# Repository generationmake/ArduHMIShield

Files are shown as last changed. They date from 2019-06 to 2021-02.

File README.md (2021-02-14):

# ArduHMIShield
ArduHMIShield with EA DOGM graphic display and joystick compatible to Arduino Uno

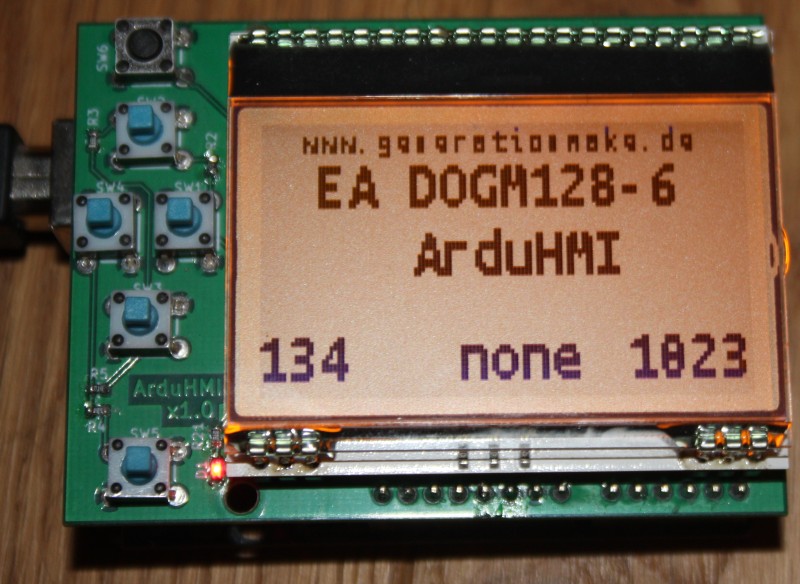
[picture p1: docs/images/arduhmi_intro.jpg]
ArduHMIShield intro


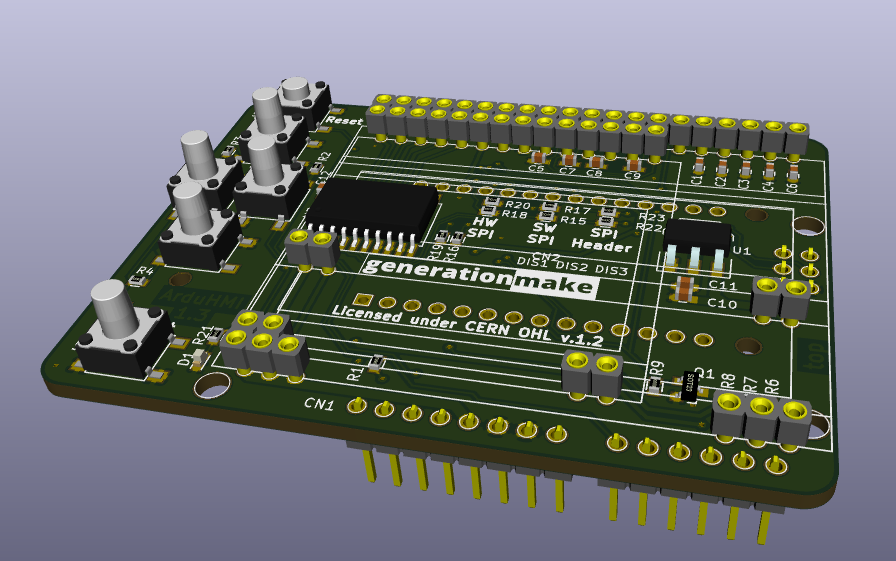
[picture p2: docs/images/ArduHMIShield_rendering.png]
ArduHMIShield rendering


### Holder

The holder is constructed using FreeCAD. It is 3D-printable. The files are in the folder `production-data`

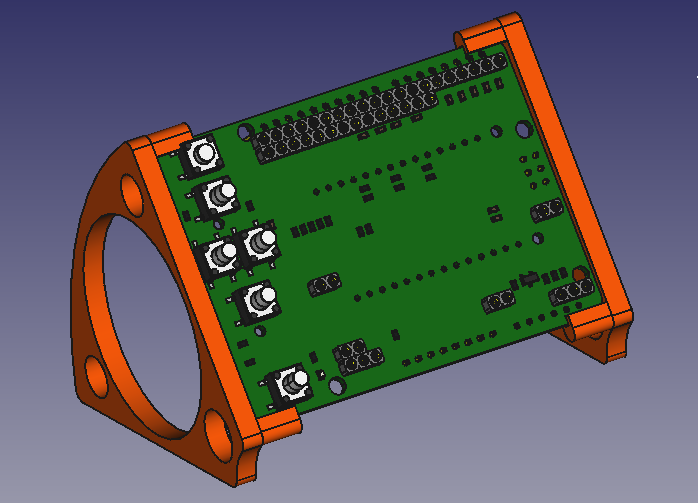
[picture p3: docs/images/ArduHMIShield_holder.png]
ArduHMIShield PCB holder


## PCB

### Top

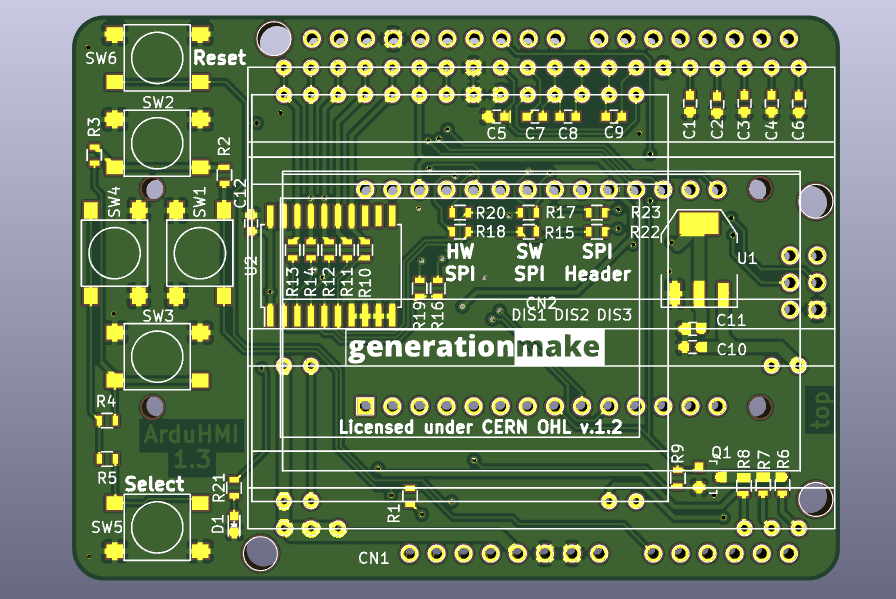
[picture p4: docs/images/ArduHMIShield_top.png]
ArduHMIShield PCB top


### Bottom

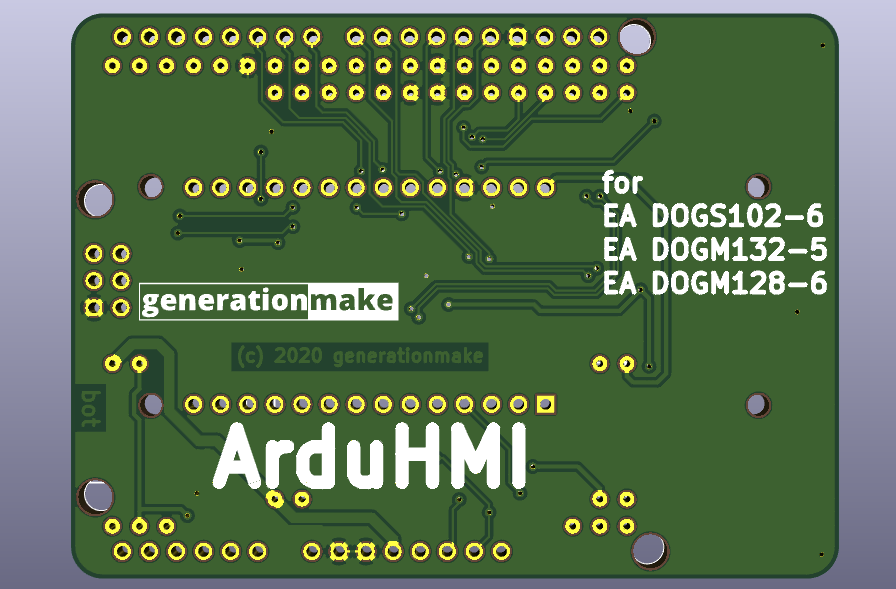
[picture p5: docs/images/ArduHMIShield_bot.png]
ArduHMIShield PCB bot


### Order options

The pcb is available at Aisler: https://aisler.net/p/FNAGFCPP

## License

This hardware is licensed under the CERN OHL v. 1.2

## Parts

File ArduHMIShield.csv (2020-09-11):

Id | Designator | Package | Quantity | Designation | Supplier and ref
1 | CN1 | ARDUINO_ISP_TOP | 1 | ARDUINO_ISP
2 | U2 | SOIC-20_7.5x12.8mm_Pitch1.27mm | 1 | 74VHC245D
3 | Q1 | SOT-23 | 1 | 2N7002
4 | C1,C2,C3,C4,C5,C6,C7,C8,C9,C10,C11 | C_0603 | 11 | 1uF
5 | R1 | R_0603 | 1 | 2k
6 | R2 | R_0603 | 1 | 330
7 | R3 | R_0603 | 1 | 620
8 | R6,R7,R8 | R_0603 | 3 | 30
9 | R9,R4,R21 | R_0603 | 3 | 1k
10 | R5 | R_0603 | 1 | 3k3
11 | DIS1 | EA_DOGM128 | 1 | EA_DOGM128-6
12 | DIS2 | EA_DOGM081_162_163_132 | 1 | EA_DOGM132-5
13 | DIS3 | EA_DOGS102 | 1 | EA_DOGS102-6
14 | U1 | SOT-223 | 1 | AZ1117IH-3.3
15 | C12 | C_0603 | 1 | 100nF
16 | R10,R11,R12,R13,R14,R15,R17,R19,R22,R23 | R_0603 | 10 | DNI
17 | R16,R18,R20 | R_0603 | 3 | 0R
18 | D1 | LED_0603 | 1 | 150060GS75000
19 | SW6 | WE_430182050816 | 1 | TAST_VER
20 | SW1,SW2,SW3,SW4,SW5 | WE_430182080816 | 5 | TAST_VER
21 | CN2 | ARDUINO_MKR_HOLES | 1 | ARDUINO_MKR
22 | L1,L2 | generationmake_logo | 2 | Label

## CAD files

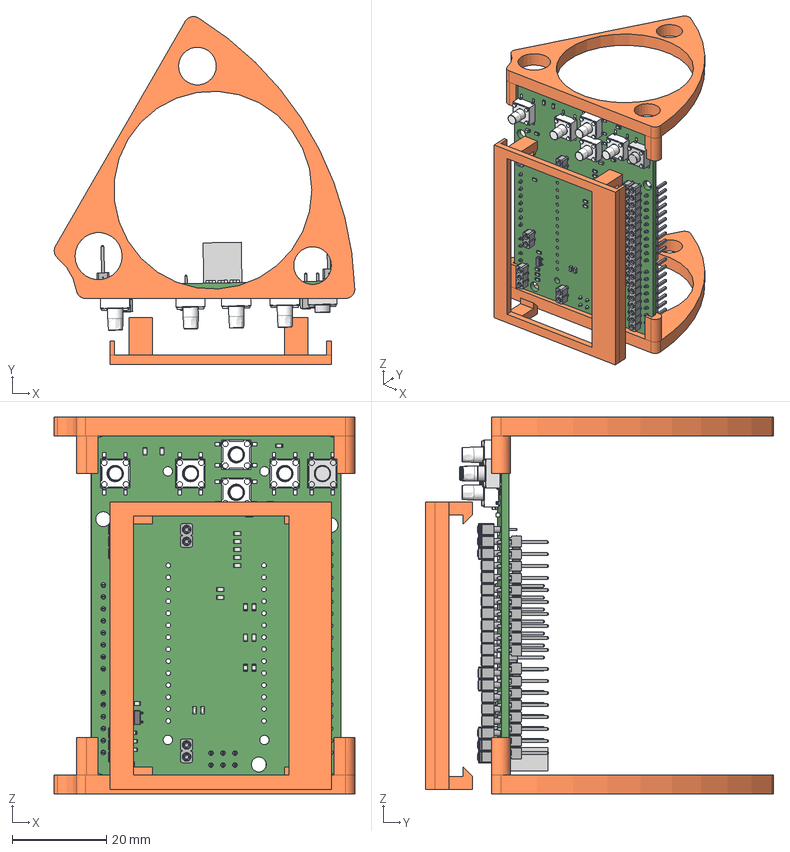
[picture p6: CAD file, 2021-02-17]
freecad_source/ArduHMI_holder.FCStd
63.8 x 73.9 x 80.0 mm
holder_right
holder_left
mainframe
clip
clip001
clip002
clip003

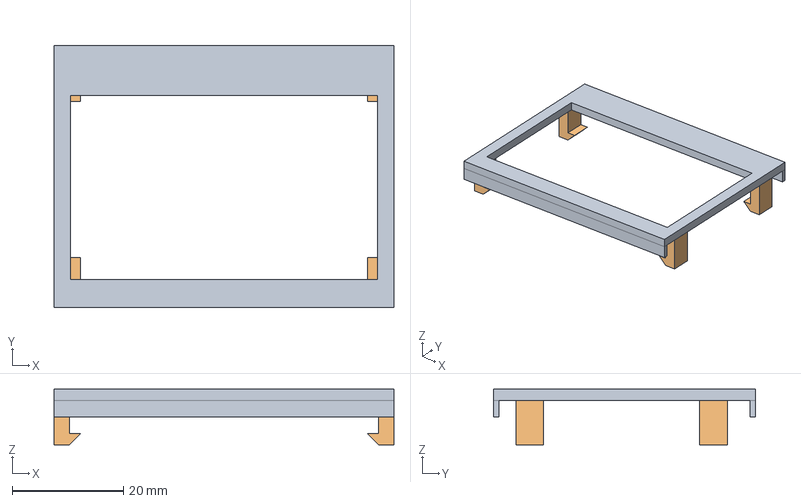
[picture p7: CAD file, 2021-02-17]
production_data/ArduHMI_displayframe_128x64.step
61.0 x 47.0 x 10.0 mm
mainframe
clip
clip001
clip002
clip003

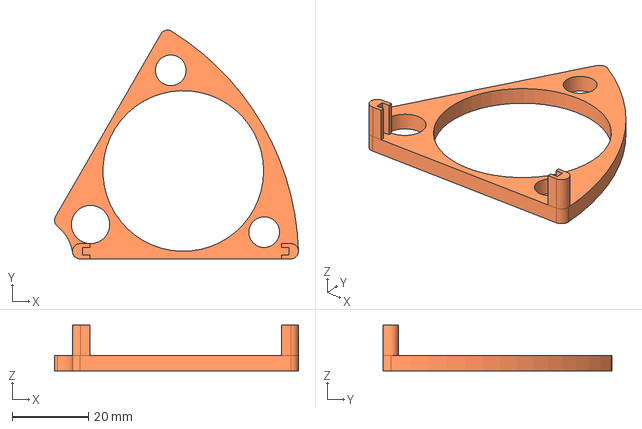
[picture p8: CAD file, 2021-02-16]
production_data/ArduHMI_holder_right.step
63.8 x 59.9 x 12.0 mm

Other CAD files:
production_data/ArduHMI_holder_left.step
production_data/ArduHMI_displayframe_128x64.stl
production_data/ArduHMI_holder_left.stl
production_data/ArduHMI_holder_right.stl

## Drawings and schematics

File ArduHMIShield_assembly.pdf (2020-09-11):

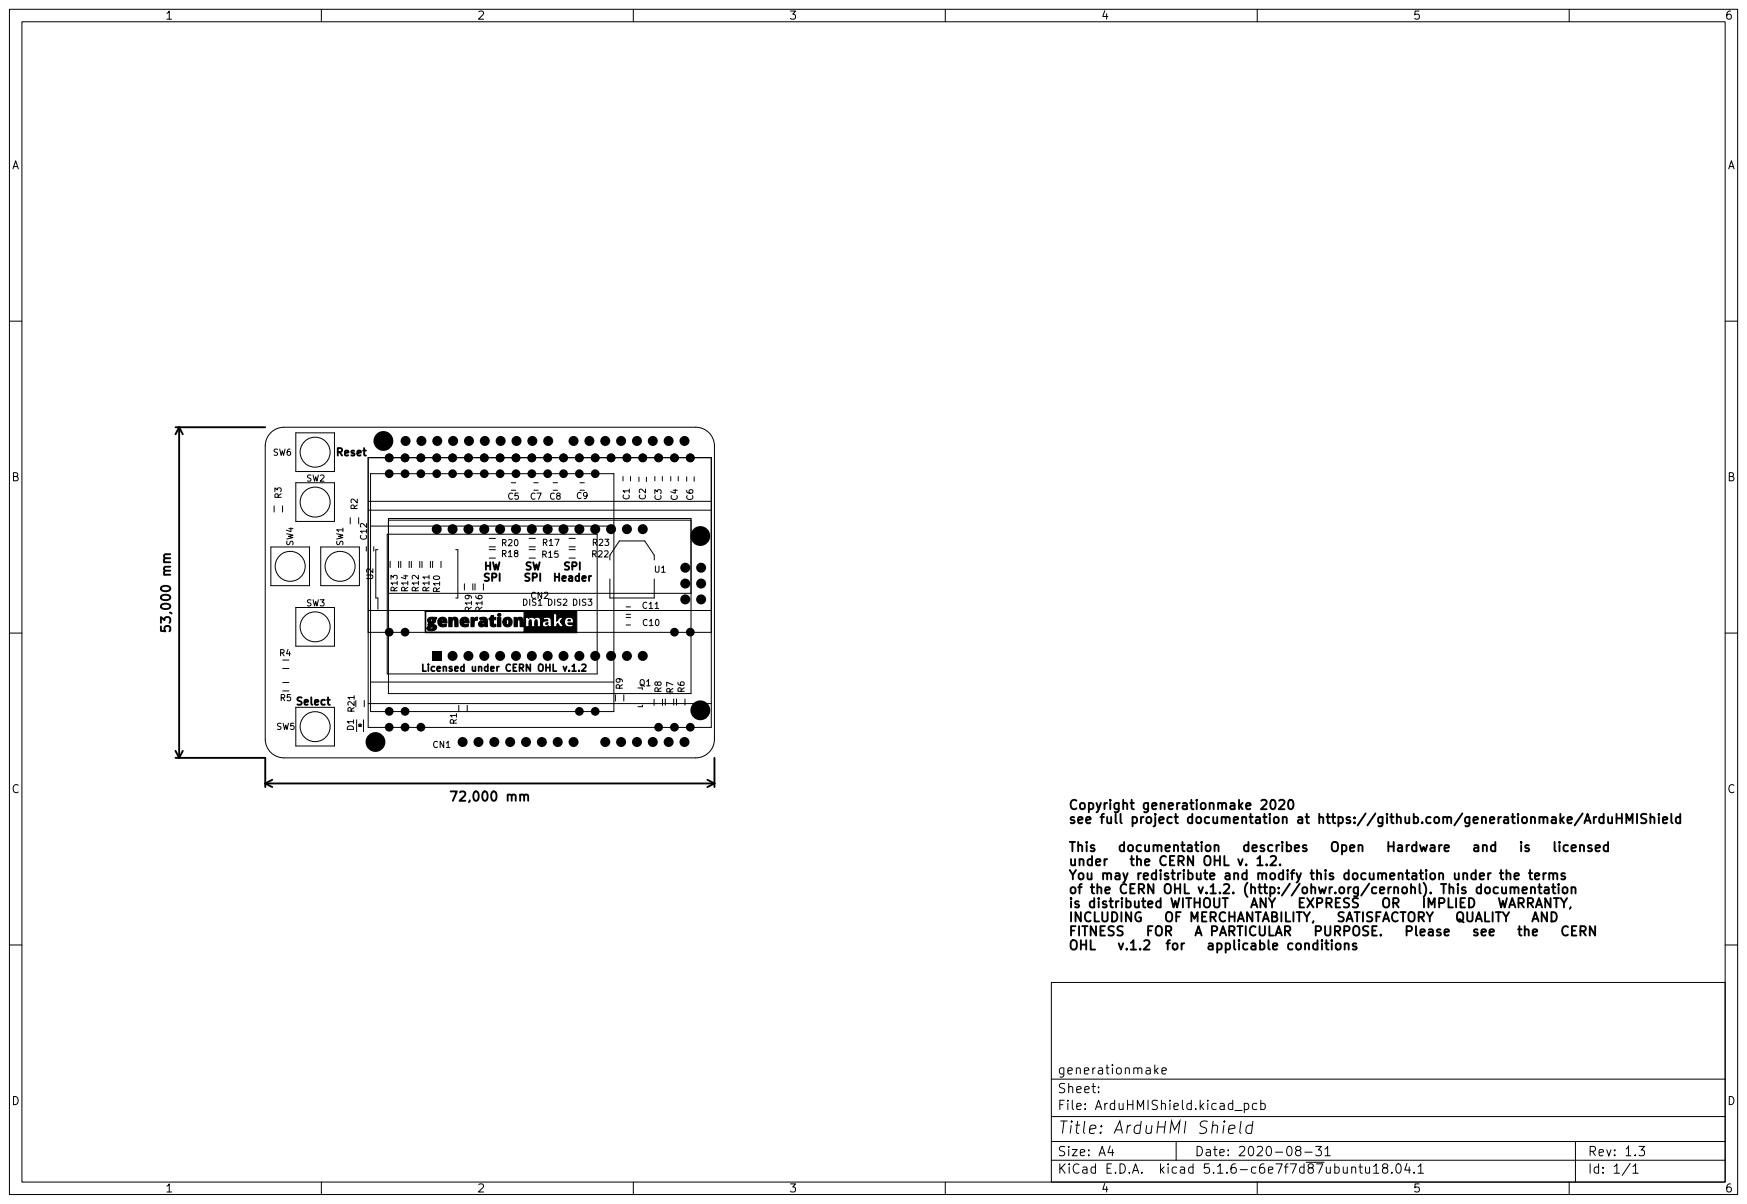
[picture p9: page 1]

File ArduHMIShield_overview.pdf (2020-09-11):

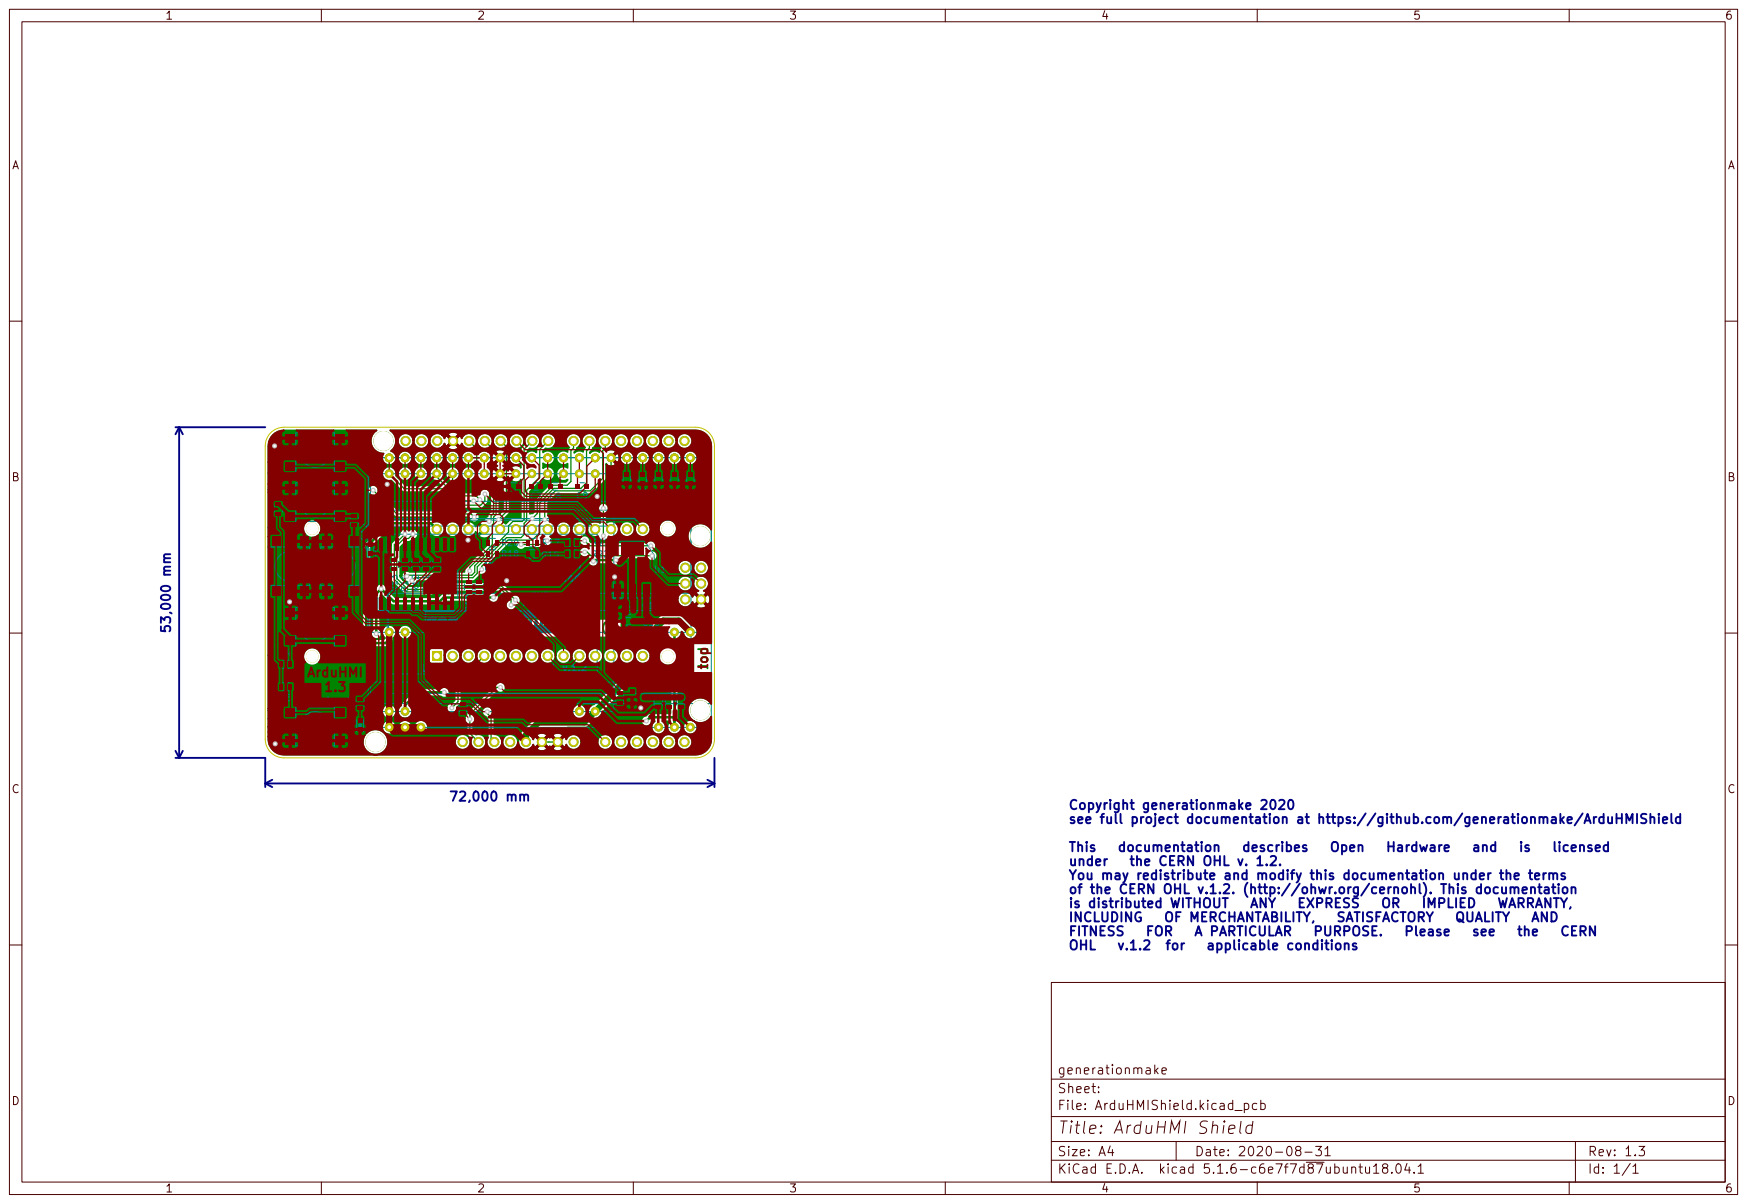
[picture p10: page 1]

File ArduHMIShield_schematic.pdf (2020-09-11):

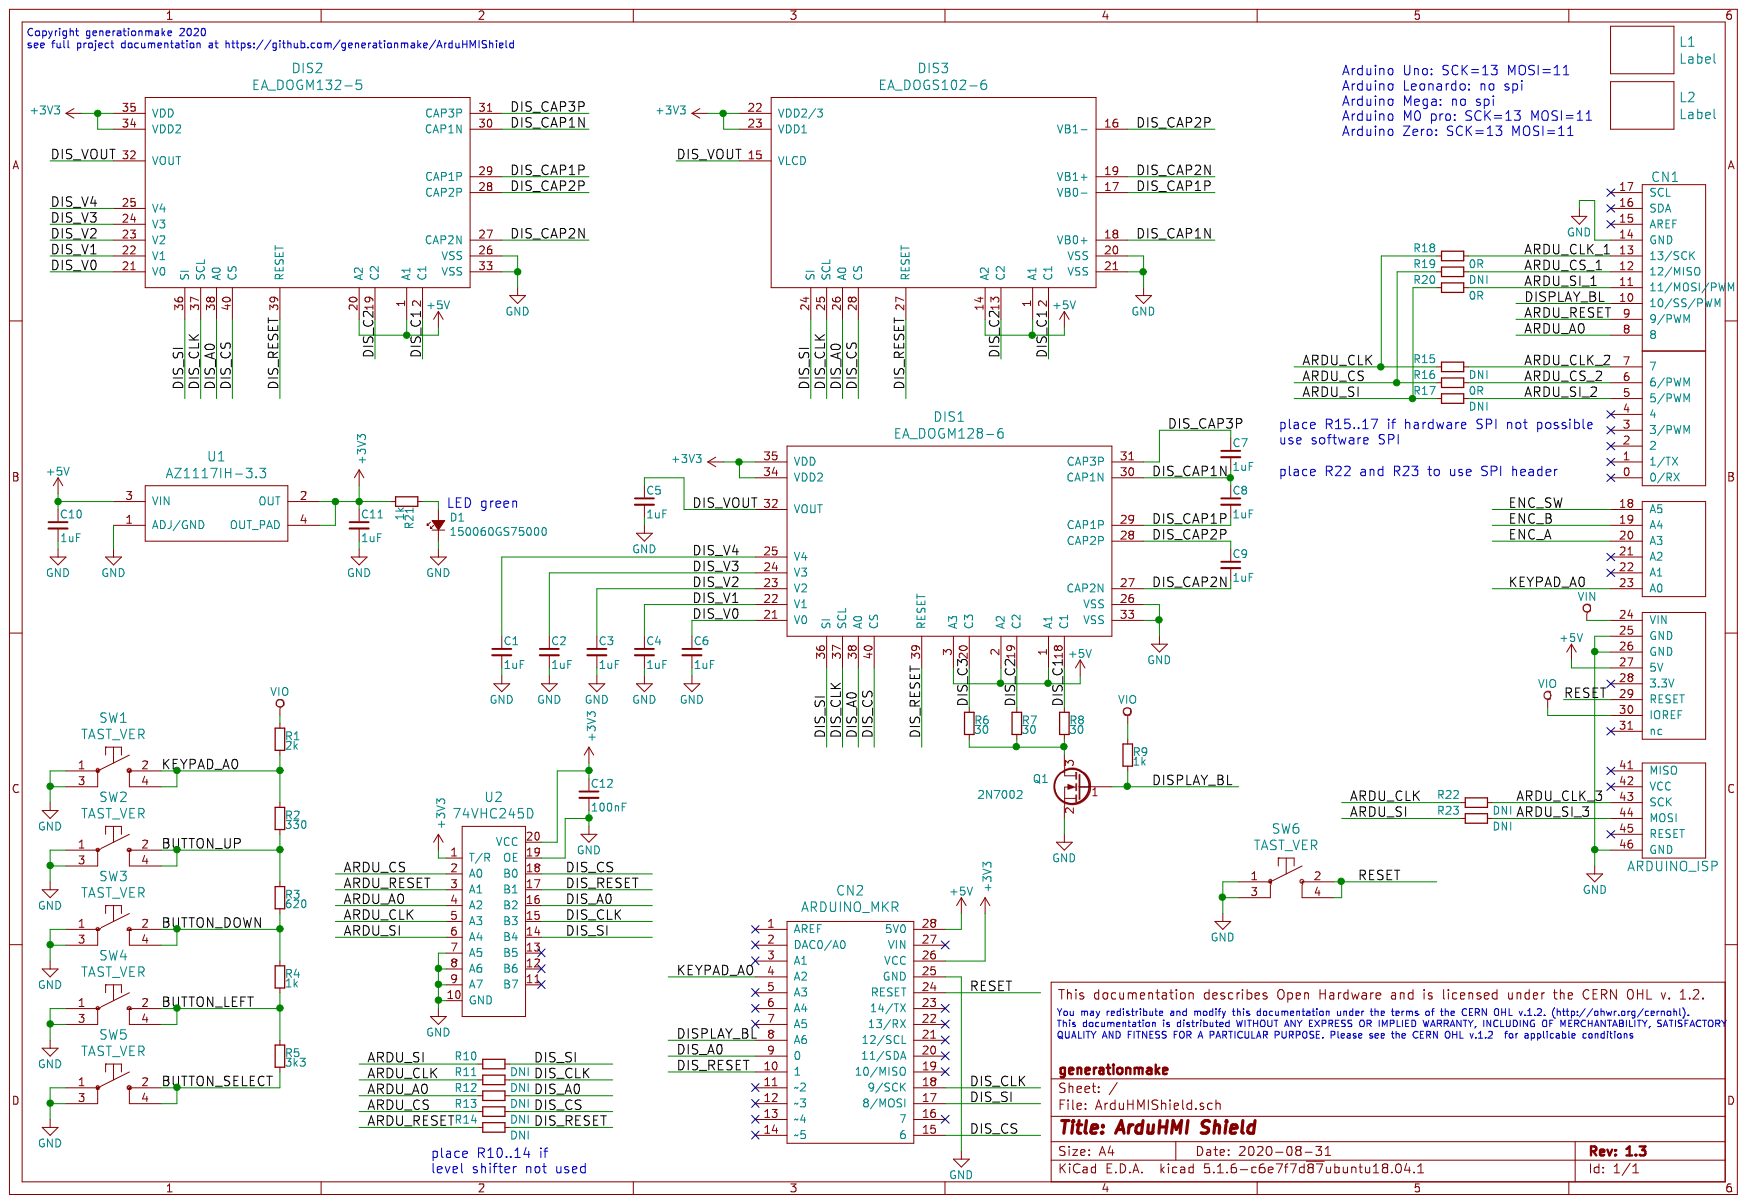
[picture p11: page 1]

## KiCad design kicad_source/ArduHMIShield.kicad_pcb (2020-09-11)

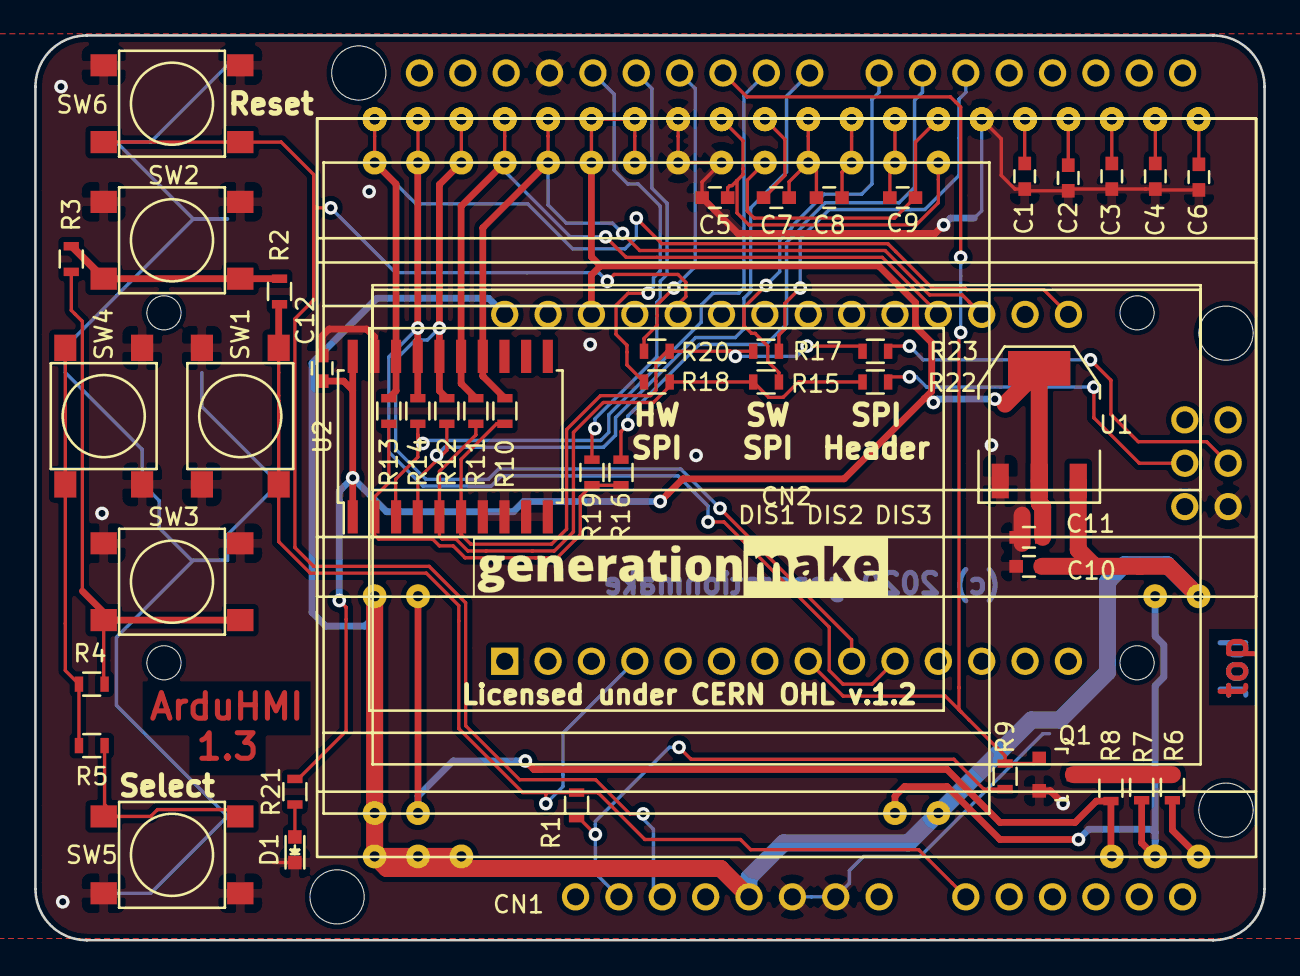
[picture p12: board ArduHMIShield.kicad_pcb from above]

Board: 2 copper layers, 72.0 x 53.0 mm, 52 parts (1 on the bottom side), 45 nets.

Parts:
C1, C2, C3, C4, C5, C6, C7, C8, C9, C10, C11: 1uF; C_0603
C12: 100nF; C_0603
CN1: ARDUINO_ISP; ARDUINO_ISP_TOP
CN2: ARDUINO_MKR; ARDUINO_MKR_HOLES
D1: 150060GS75000; LED_0603
DIS1: EA_DOGM128-6; EA_DOGM128
DIS2: EA_DOGM132-5; EA_DOGM081_162_163_132
DIS3: EA_DOGS102-6; EA_DOGS102
L1, L2: Label; generationmake_logo
Q1: 2N7002; SOT-23
R1: 2k; R_0603
R2: 330; R_0603
R3: 620; R_0603
R4, R9, R21: 1k; R_0603
R5: 3k3; R_0603
R6, R7, R8: 30; R_0603
R10, R11, R12, R13, R14, R15, R17, R19, R22, R23: DNI; R_0603
R16, R18, R20: 0R; R_0603
SW1, SW2, SW3, SW4, SW5: TAST_VER; WE_430182080816
SW6: TAST_VER; WE_430182050816
U1: AZ1117IH-3.3; SOT-223
U2: 74VHC245D; SOIC-20_7.5x12.8mm_Pitch1.27mm

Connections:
+3V3: C11.1, C12.1, CN2.26, DIS1.34, DIS1.35, DIS2.34, DIS2.35, DIS3.22, DIS3.23, R21.2, U1.2, U1.4, U2.1, U2.20
+5V: C10.1, CN1.27, CN2.28, DIS1.1, DIS1.2, DIS1.3, DIS2.1, DIS2.20, DIS3.1, DIS3.14, U1.3
/ARDU_A0: CN1.8, R12.2, U2.4
/ARDU_CLK: R11.2, R15.2, R18.2, R22.2, U2.5
/ARDU_CLK_1: CN1.13, R18.1
/ARDU_CLK_2: CN1.7, R15.1
/ARDU_CLK_3: CN1.43, R22.1
/ARDU_CS: R13.2, R16.2, R19.2, U2.2
/ARDU_CS_1: CN1.12, R19.1
/ARDU_CS_2: CN1.6, R16.1
/ARDU_RESET: CN1.9, R14.2, U2.3
/ARDU_SI: R10.2, R17.2, R20.2, R23.2, U2.6
/ARDU_SI_1: CN1.11, R20.1
/ARDU_SI_2: CN1.5, R17.1
/ARDU_SI_3: CN1.44, R23.1
/BUTTON_DOWN: R3.2, R4.1, SW3.2, SW3.4
/BUTTON_LEFT: R4.2, R5.1, SW4.2, SW4.4
/BUTTON_SELECT: R5.2, SW5.2, SW5.4
/BUTTON_UP: R2.2, R3.1, SW2.2, SW2.4
/DISPLAY_BL: CN1.10, CN2.8, Q1.1, R9.2
/DIS_A0: CN2.9, DIS1.38, DIS2.38, DIS3.26, R12.1, U2.16
/DIS_C1: DIS1.18, DIS2.2, DIS3.2, R8.1
/DIS_C2: DIS1.19, DIS2.19, DIS3.13, R7.1
/DIS_C3: DIS1.20, R6.1
/DIS_CAP1N: C7.2, C8.1, DIS1.30, DIS2.30, DIS3.18
/DIS_CAP1P: C8.2, DIS1.29, DIS2.29, DIS3.17
/DIS_CAP2N: C9.2, DIS1.27, DIS2.27, DIS3.19
/DIS_CAP2P: C9.1, DIS1.28, DIS2.28, DIS3.16
/DIS_CAP3P: C7.1, DIS1.31, DIS2.31
/DIS_CLK: CN2.18, DIS1.37, DIS2.37, DIS3.25, R11.1, U2.15
/DIS_CS: CN2.15, DIS1.40, DIS2.40, DIS3.28, R13.1, U2.18
/DIS_RESET: CN2.10, DIS1.39, DIS2.39, DIS3.27, R14.1, U2.17
/DIS_SI: CN2.17, DIS1.36, DIS2.36, DIS3.24, R10.1, U2.14
/DIS_V0: C6.1, DIS1.21, DIS2.21
/DIS_V1: C4.1, DIS1.22, DIS2.22
/DIS_V2: C3.1, DIS1.23, DIS2.23
/DIS_V3: C2.1, DIS1.24, DIS2.24
/DIS_V4: C1.1, DIS1.25, DIS2.25
/DIS_VOUT: C5.1, DIS1.32, DIS2.32, DIS3.15
/KEYPAD_A0: CN1.23, CN2.4, R1.2, R2.1, SW1.2, SW1.4
/RESET: CN1.29, CN2.24, SW6.2, SW6.4
GND: C1.2, C2.2, C3.2, C4.2, C5.2, C6.2, C10.2, C11.2, C12.2, CN1.14, CN1.25, CN1.26, CN1.46, CN2.25, D1.1, DIS1.26, DIS1.33, DIS2.26, DIS2.33, DIS3.20, DIS3.21, Q1.2, SW1.1, SW1.3, SW2.1, SW2.3, SW3.1, SW3.3, SW4.1, SW4.3, SW5.1, SW5.3, SW6.1, SW6.3, U1.1, U2.7, U2.8, U2.9, U2.10, U2.19
unnamed: D1.2, R21.1
unnamed: Q1.3, R6.2, R7.2, R8.2
VIO: CN1.30, R1.1, R9.1

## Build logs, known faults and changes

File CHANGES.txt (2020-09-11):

ArduHMI - Graphic HMI for Arduino
see full project documentation at http://arduhmi.generationmake.de or https://github.com/generationmake/ArduHMIShield

changes

version 1.0 - 2019-02-20
* initial release

version 1.1 - 2019-06-24
* changed switches to SMD version to avoid short circuit with USB connector of Arduino Uno
* changed level shifter to 74LHC245D because of better availability and easier soldering

version 1.2 - 2019-08-23
* removed GND connection on pin 2 of SW5
* corrected silk screen of R4 and R5
* added Arduino SPI header and R22 and R23

version 1.3 - 2020-08-31
* added connector for Arduino MKR

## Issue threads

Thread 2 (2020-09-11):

connect VIO to +3V3 with Arduino MKR

generationmake, 2020-09-11:
The Arduino MKR form factor has no IOREF signal. All signals have 3.3V levels. So, VIO needs to be tight to the 3.3V rail when the MKR connector is used. Add additional 0 Ohm resistor.

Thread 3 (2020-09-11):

Add touch controller

generationmake, 2020-09-11:
There exists a touch foil for some of the displays. A touch controller could be added to use this feature. Since there are not many GPIOs left on the Arduino connector best option would be to use I2C.

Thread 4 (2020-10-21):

add uSD socket

generationmake, 2020-10-21:
level shifting to 3.3V is already done. so this shouldn't be too much of an issue.

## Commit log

2018-10-04 added project files
    [ArduHMIShield-2018-10-01-00-18-25.sch, ArduHMIShield-2018-10-01-00-20-07.sch, ArduHMIShield.kicad_pcb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]
2018-10-04 reworked schematic and layout, both seem to be finished
    [ArduHMIShield.kicad_pcb, ArduHMIShield.sch]
2018-10-04 generated pdf schematic
2018-10-07 updated schematic and layout
    [ArduHMIShield.kicad_pcb, ArduHMIShield.sch]
2018-10-08 finished layout and generated output files
    [ArduHMIShield-B.Cu.gbl, ArduHMIShield-B.Mask.gbs, ArduHMIShield-Edge.Cuts.gm1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]
2019-06-24 added gerber for version 1.0
2019-06-24 updated pcb and schematic to version 1.1, see changes in CHANGES.txt
    [ArduHMIShield.kicad_pcb, ArduHMIShield.sch]
2019-06-24 generated gerber and pdf files
    [ArduHMIShield-B.Cu.gbl, ArduHMIShield-B.Mask.gbs, ArduHMIShield-B.SilkS.gbo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]
2019-06-24 added bom
    [ArduHMIShield.csv]
2019-06-28 completed reichelt BOM, added source code of scrolling badge
2019-06-28 updated BOM with farnell and digikey order numbers
2019-06-29 updated design files to better support Aisler
    [ArduHMIShield.kicad_pcb, ArduHMIShield.sch]
2019-08-23 removed short cut, corrected silkscreen
    [ArduHMIShield.kicad_pcb]
2019-08-23 added Arduino SPI header, updated all files
    [ArduHMIShield-2018-10-01-00-18-25.sch, ArduHMIShield-2018-10-01-00-20-07.sch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]
2019-10-19 updated layout to get nicer 3D model
    [ArduHMIShield.kicad_pcb, ArduHMIShield.sch]
2019-10-20 started sub project MKRHMIShield
    [MKRHMIShield.csv, MKRHMIShield.kicad_pcb, MKRHMIShield.sch]
2019-10-20 exchanged switches with a joystick
    [MKRHMIShield.kicad_pcb, MKRHMIShield.sch]
2019-10-21 added 3D body of display
    [MKRHMIShield.kicad_pcb]
2019-11-19 copied new pcb HMIFeatherWing from MKRHMIShield
    [HMIFeatherWing.csv, HMIFeatherWing.kicad_pcb, HMIFeatherWing.sch]
2019-11-19 made schematic and layout
    [HMIFeatherWing.kicad_pcb, HMIFeatherWing.sch]
2019-12-04 checked pins to fit to other feather wings, used smaller reset, corrected joystick orientation, connected backlight, made board smaller, finished layout
    [HMIFeatherWing.kicad_pcb, HMIFeatherWing.sch]
2019-12-04 update title block and generated pdfs
    [HMIFeatherWing.kicad_pcb, HMIFeatherWing.sch]
2020-08-19 removed files not belonging to project
    [HMIFeatherWing.csv, HMIFeatherWing.kicad_pcb, HMIFeatherWing.sch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]
2020-08-19 moved files to correct folder
    [ArduHMIShield-B.Cu.gbl, ArduHMIShield-B.Mask.gbs, ArduHMIShield-B.SilkS.gbo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]
2020-08-19 removed gerber files
    [ArduHMIShield-B.Cu.gbl, ArduHMIShield-B.Mask.gbs, ArduHMIShield-B.SilkS.gbo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]
2020-08-30 added Arduino MKR conector
    [ArduHMIShield.kicad_pcb, ArduHMIShield.sch]
2020-08-30 updated layout
    [ArduHMIShield.kicad_pcb]
2020-08-30 added holes for MKR connector
    [ArduHMIShield.kicad_pcb, ArduHMIShield.sch]
2020-08-30 rounded edge of pcb
    [ArduHMIShield.kicad_pcb]
2020-08-30 updated order numbers
    [ArduHMIShield.kicad_pcb, ArduHMIShield.sch]
2020-08-30 generated pdfs, updated changes file
    [ArduHMIShield.csv, ArduHMIShield.kicad_pcb, ArduHMIShield.sch]
2020-08-30 added images of pcb
2020-08-30 added step file of board
2021-02-14 added freecad project for holder
    [ArduHMI_holder.FCStd]
2021-02-14 added production data for holder
    [ArduHMI_holder_left.step, ArduHMI_holder_left.stl, ArduHMI_holder_right.step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]
2021-02-16 slightly updated holder, made slot for pcb wider
    [ArduHMI_holder.FCStd, ArduHMI_holder_left.step, ArduHMI_holder_left.stl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]
2021-02-17 created and tested display frame
    [ArduHMI_displayframe.stl, ArduHMI_holder.FCStd]
2021-02-17 added step and .gitignore
    [ArduHMI_displayframe_128x64.step, ArduHMI_displayframe_128x64.stl, ArduHMI_holder.FCStd]

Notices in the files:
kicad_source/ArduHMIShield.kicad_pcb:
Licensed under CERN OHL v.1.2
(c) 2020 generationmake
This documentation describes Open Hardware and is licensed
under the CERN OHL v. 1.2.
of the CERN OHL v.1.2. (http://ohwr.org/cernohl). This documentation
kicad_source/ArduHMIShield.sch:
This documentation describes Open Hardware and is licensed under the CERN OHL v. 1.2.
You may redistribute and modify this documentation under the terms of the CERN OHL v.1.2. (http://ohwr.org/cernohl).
